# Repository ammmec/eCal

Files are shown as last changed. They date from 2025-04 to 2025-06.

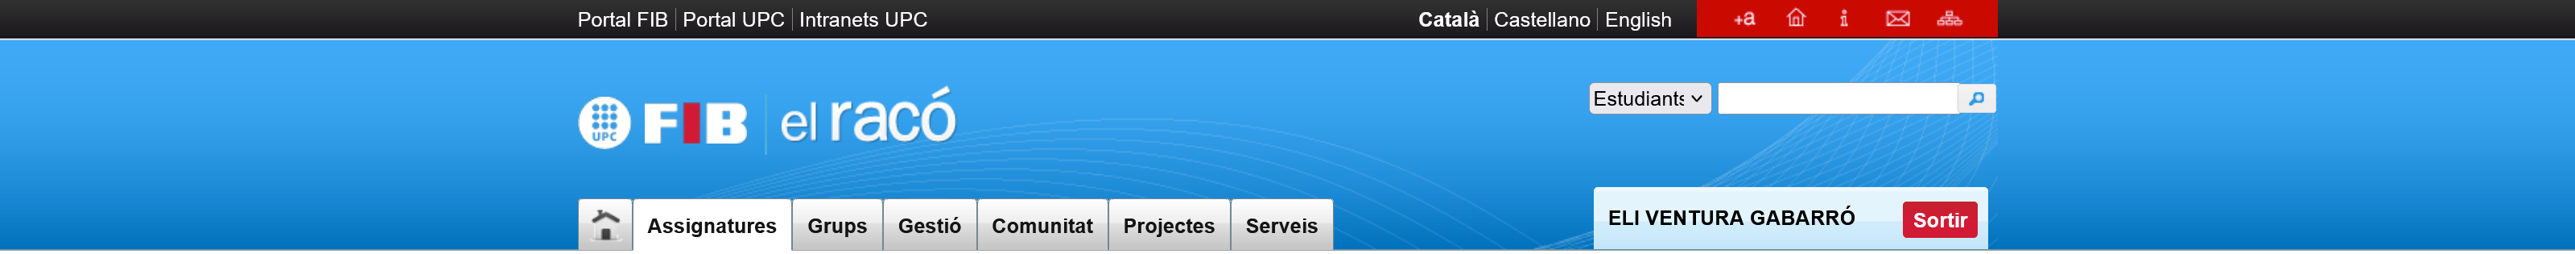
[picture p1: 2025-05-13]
raco/Racó de la FIB_fitxers/header.png

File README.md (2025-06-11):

# eCal
This repository contains the necessary source code to reproduce a dynamic e-paper classroom schedule, made as a bachelor thesis in Facultat d'Informàtica de Barcelona, UPC. It is meant for the classrooms of the faculty (FIB), but can be adapted if necessary.

## Contents
- [Features](#features)
- [Components](#components)
  * [Wiring](#wiring)
- [Project Structure](#project-structure)

## Features
- Ultra-low power.
- Long battery life.
- 3-color e-paper display (red, black & white).
- Easily rechargable.
- 3D printed fitted casing.

## Components
The following components were used to create the project:
- 7.5inch e-paper (B) by Waveshare
- Firebeetle 2 ESP32-C6 by DFRobot
- Li-Po battery 3.7V 2500mAh with JST-PH connector
- Solar Panel - 5V 60mA - 68x37mm

### Wiring
To correctly setup the device, use the following wiring:
a61561e88b862fee8ae2c5b064a682b26159ba7b
Other connections can be used, as long as the pin definition in eCal/schedule_lib.h is changed to reflect those changes.

## Project Structure
The repository has three folders. Each are linked to a specific device/server.
- [eCal](https://github.com/ammmec/eCal/tree/main/eCal): source code for the microcontroller.
- [eCal_PC](https://github.com/ammmec/eCal/tree/main/eCal_PC): source code for the daily script.
- [raco](https://github.com/ammmec/eCal/tree/main/raco): proposed addition for _el Racó_.
- [stl](https://github.com/ammmec/eCal/tree/main/stl): casing files to 3D print.
Inside the eCal and eCal_PC folders, a file needs to be added, which were ommitted in the repository for safety reasons.
The template for the file in eCal, called wifi_secure.h is the following:
```C
#ifndef WIFI_SECURE_H
#define WIFI_SECURE_H
// WiFi
inline const char* ssid = WIFI NAME GOES HERE;
inline const char* password = PASSWORD OF WIFI GOES HERE;

// MQTT Broker
inline const char *mqtt_broker = LINK TO MQTT BROKER;
inline const char *topic [] = {"+/A6/0/A6001", "+/A6/0", "+/A6", "+"};
inline const char *mqtt_username = USERNAME IN BROKER;
inline const char *mqtt_password = PASSWORD IN BROKER;
inline const int mqtt_port = BROKER'S PORT;
inline static const char ca_cert[]
PROGMEM = R"EOF(
  CERTIFICATE FOR SECURE CONNECTION
)EOF";
#endif
```
And the template for the file in eCal_PC, called data_secure.py:
```python
CLIENT_ID = PUBLIC APPLICATION OF THE RACÓ'S API

username = MQTT USERNAME
password = MQTT PASSWORD

broker = LINK TO MQTT BROKER
port = BROKER'S PORT
```

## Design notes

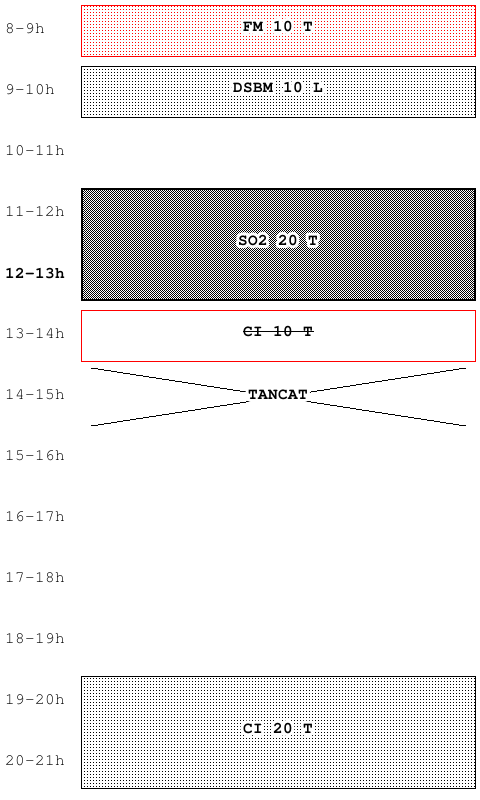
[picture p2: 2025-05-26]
eCal_PC/config/img/minimalist.png

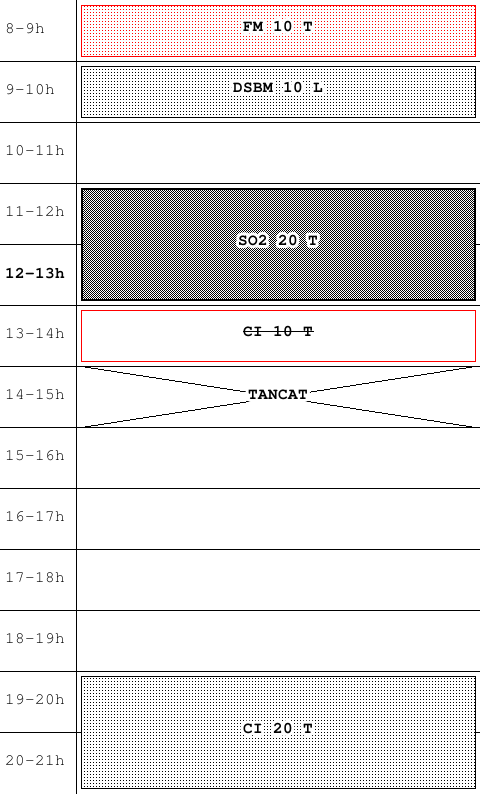
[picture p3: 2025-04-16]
eCal_PC/config/img/minimalist_lines.png

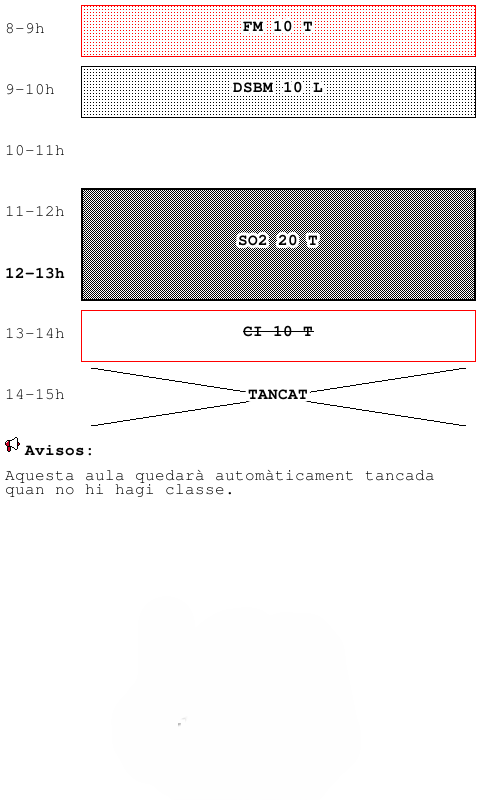
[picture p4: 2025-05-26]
eCal_PC/config/img/simple.png

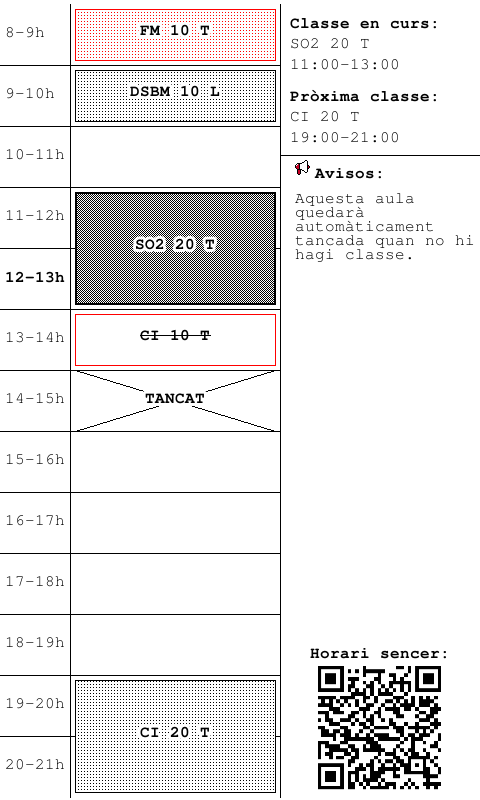
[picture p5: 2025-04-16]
eCal_PC/config/img/verbose_lines.png

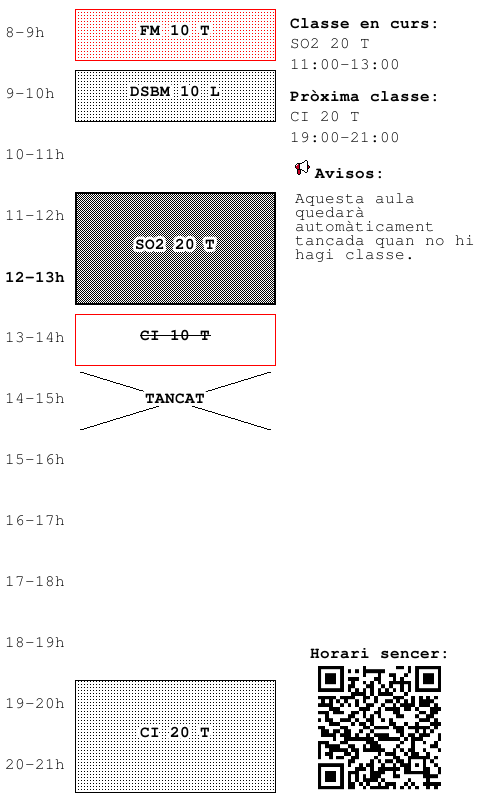
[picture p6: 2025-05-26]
eCal_PC/config/img/verbose.png

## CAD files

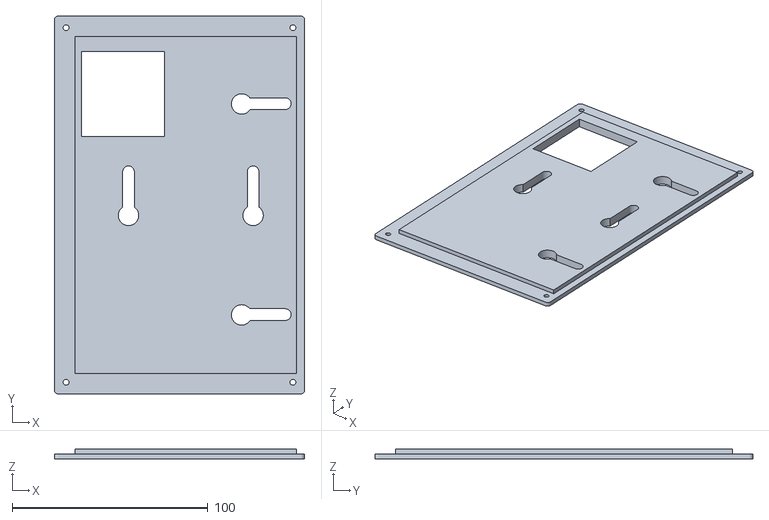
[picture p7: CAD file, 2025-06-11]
stl/Back Cover.stl
127.9 x 193.2 x 5.00

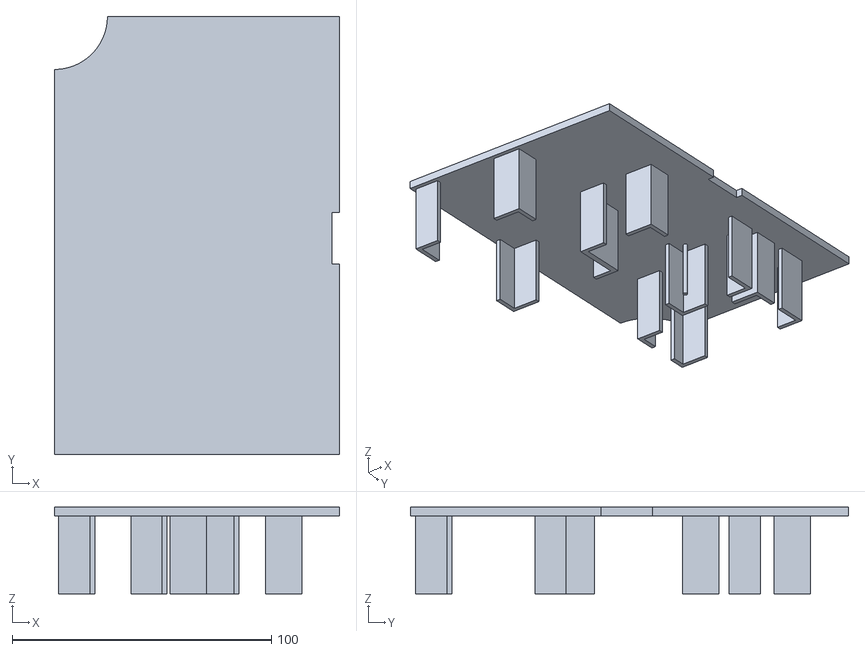
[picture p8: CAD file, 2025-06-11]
stl/Holding Section.stl
110.0 x 169.0 x 33.5

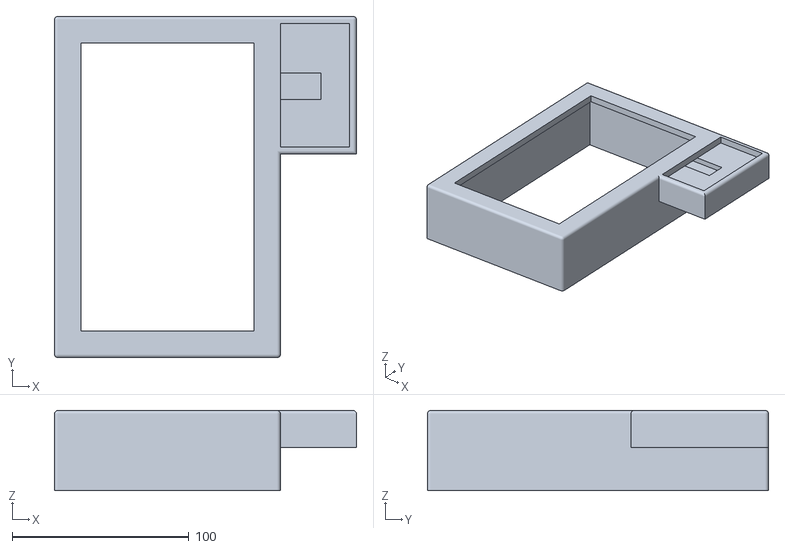
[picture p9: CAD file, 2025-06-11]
stl/Frame.stl
170.9 x 193.2 x 45.3

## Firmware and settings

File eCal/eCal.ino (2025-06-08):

#include "mqtt.h"
#define uS2M  1000000ULL*60  // 1000000ULL // Conversion from micro seconds to minutes
// Time the microcontroller will be asleep for in different moments
#define RETRY_SLEEP (((rawConfig >> 4) & 0x03F) == 0x3F) ? 5U : (rawConfig >> 4) & 0x03F  //Default value if not changed yet
#define NIGHT_SLEEP 9U                        // 10 hours (21-07): 9 + offset
#define WEEKEND_SLEEP 57U                     // 58 hours (10 for morning, 48 for weekend): 57 + offset

int16_t durations[NUM_CLASSES] = { 0, 0, 0, 0, 0, 0, 0, 0, 0, 0, 0, 0, 0 };
char classes[NUM_CLASSES][32] = { "", "", "", "", "", "", "", "", "", "", "", "", "" };
change_t changed[NUM_CLASSES] = { NONE, NONE, NONE, NONE, NONE, NONE, NONE, NONE, NONE, NONE, NONE, NONE, NONE };
char announcements[256];

RTC_DATA_ATTR bool gotSchedule = false;

void deepSleep(uint16_t minutes) {
  esp_sleep_enable_timer_wakeup(minutes * uS2M);
  #ifdef DEBUG
  Serial.println("Setup ESP32 to sleep for every " + String(minutes) + " minutes");

  Serial.println("Going to sleep now");
  #endif
  Serial.flush();
  esp_deep_sleep_start();
}

void setup() {
  #ifdef DEBUG
  Serial.begin(115200);
  delay(1000);  //Take some time to open up the Serial Monitor

  Serial.print("Good morning! Got schedule? ");
  Serial.println(gotSchedule);
  #endif

  setupLayout();

  uint8_t hourSleep = 60;
  connectWiFi(hourSleep);

  if (currentHour <= LAST_HOUR) {
    setupMQTT();

    if (!gotSchedule) {
      if (getSchedule(classes, durations)) {
        gotSchedule = true;
        needRefresh = true;
      } else {
        if (needRefresh) {
          drawNoSchedule();
          needRefresh = false;
        }
        #ifdef DEBUG
        Serial.println("Did not get schedule... Retry sleep!");
        #endif
        disconnectMQTT();
        disconnectWiFi();
        deepSleep(RETRY_SLEEP);  // If it did not manage to get the full schedule, try again after some time
      }
    }

    getDetails();
    disconnectMQTT();
    disconnectWiFi();

    // Refresh display
    #ifdef DEBUG
    Serial.println("Printing schedule");
    #endif
  
    drawSchedule(classes, durations, announcements, changed);
  }
  else {
    disconnectWiFi();

    gotSchedule = false;
    restartData(); // prepare data for a new day (e.g. initialize arrays to 0)

    if (weekday == FRIDAY) {
      #ifdef DEBUG
      Serial.println("Weekend sleep!");
      #endif
      // clearScreen();
      deepSleep(WEEKEND_SLEEP+hourSleep);
    }
    #ifdef DEBUG
    Serial.println("Night sleep!");
    #endif
    deepSleep(NIGHT_SLEEP+hourSleep);
  }

  needRefresh = false;
  #ifdef DEBUG
  Serial.println("Hour sleep!");
  #endif
  deepSleep(hourSleep);
}

void loop() {}

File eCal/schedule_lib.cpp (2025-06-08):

#include "schedule_lib.h"

// Display constructor
GxEPD2_3C< GxEPD2_750c_Z08, GxEPD2_750c_Z08::HEIGHT / 4 > display(GxEPD2_750c_Z08(/*CS=*/CS, /*DC=*/DC, /*RST=*/RST, /*BUSY=*/BUSY));  // GDEW075Z08 800x480, GD7965

uint16_t displayHeight;
uint16_t displayWidth;
LayoutConfig config;
uint16_t currentHour;
WEEKDAYS weekday = MONDAY;  // Assumes it starts on a Monday
char curr_class_pos;

// Variables to check if the schedule needs to be refreshed
char prevStartHour;
uint16_t rawConfig = 0x107F; //0b000'1'0'0'000111'1111;

bool updatedInfo = true;
RTC_DATA_ATTR bool needRefresh = true;

bool connectWiFi(uint8_t& minutesTilNextHour) {
  WiFi.begin(ssid, password);
  unsigned int startAttempt = millis();
  while (WiFi.status() != WL_CONNECTED && millis() - startAttempt < 7000) {  // Try to connect for 7 seconds. If it fails, put a WiFi error message
    #ifdef DEBUG
    Serial.print(".");
    #endif
    delay(500);
  }
  #ifdef DEBUG
  Serial.println();
  #endif
  if (WiFi.status() != WL_CONNECTED) {
    updatedInfo = false;
    return false;
  } else updatedInfo = true;
  if (minutesTilNextHour != 255) minutesTilNextHour = updateCurrentHour();
  #ifdef DEBUG
  Serial.println("\nWiFi connected.");
  #endif
  return true;
}

bool connectWiFi() {
  uint8_t dummy = 255;
  return connectWiFi(dummy);
}

void disconnectWiFi() {
  WiFi.disconnect(true);
  WiFi.mode(WIFI_OFF);
  #ifdef DEBUG
  Serial.println("Wifi disconnected.");
  #endif
}

void restartData() {
  needRefresh = true;

  // Initialize durations to 0, no changes and no announcements
  for (int i = 0; i < NUM_CLASSES; ++i) {
    durations[i] = 0;
    changed[i] = NONE;
  }
  announcements[0] = '\0';
}

// Must be called before drawing schedule for the first time. Sets up the indicated schedule
void setupLayout(uint16_t settings, bool changed) {
  Layout layout = static_cast<Layout>(settings>>13);
  bool lines = (settings>>12)&0x01;
  bool staticSchedule = (settings>>11)&0x01;
  bool saveEnergy = (settings>>10)&0x01;

  #ifdef DEBUG
  Serial.print("Layout: ");
  Serial.println(settings>>13);
  Serial.print("Lines: ");
  Serial.println(lines);
  Serial.print("SaveEnergy: ");
  Serial.println(saveEnergy);
  Serial.print("staticSchedule: ");
  Serial.println(staticSchedule);
  #endif

  display.setRotation(layout == HORIZONTAL_LAYOUT ? 2 : 1);
  displayHeight = display.height();
  displayWidth = display.width();
  if (!changed) return;

  switch (layout) {
    case DEFAULT_LAYOUT:
      config = {
        .showLines = lines,
        .showQR = true,
        .showAnnouncements = true,
        .showCurrNext = false,
        .saveEnergy = saveEnergy,
        .staticSchedule = saveEnergy || staticSchedule,  // If energy saver is on, the schedule will be static to save energy

        .numClassesDisplayed = 7,

        .topMargin = 0,
        .bottomMargin = 0,

        .endClassLine = displayWidth,
        .startAnnouncementsLine = 0,

        .name = "df"
      };
      config.classWidth = (displayWidth - config.hourLine) - (displayWidth - config.hourLine) % CLASS_BP_WIDTH;  // Take all usable space
      config.classHeight = ((displayHeight / 2) / config.numClassesDisplayed);                                   // Take half the screen
      config.rows[0] = config.classHeight * config.numClassesDisplayed + MARGIN * 3;
      break;

    case MINIMALIST_LAYOUT:
      config = {
        .showLines = lines,
        .showQR = false,
        .showAnnouncements = false,
        .showCurrNext = false,
        .saveEnergy = saveEnergy,
        .staticSchedule = false,  // Avoids a bug if it is true

        .numClassesDisplayed = 13,

        .endClassLine = displayWidth,
        .startAnnouncementsLine = 0,

        .name = "mn"
      };
      config.classHeight = (displayHeight / config.numClassesDisplayed);
      config.classWidth = (displayWidth - config.hourLine) - (displayWidth - config.hourLine) % CLASS_BP_WIDTH;
      config.bottomMargin = (displayHeight - (config.classHeight * config.numClassesDisplayed)) / 2;
      config.topMargin = config.bottomMargin + ((displayHeight - config.classHeight * config.numClassesDisplayed) % 2 != 0);
      break;

    case SIMPLE_LAYOUT:
      config = {
        .showLines = lines,
        .showQR = false,
        .showAnnouncements = false,
        .showCurrNext = false,
        .saveEnergy = saveEnergy,
        .staticSchedule = false,

        .numClassesDisplayed = 13,

        .endClassLine = displayWidth,
        .startAnnouncementsLine = 0,

        .name = "sp"
      };
      config.classHeight = (displayHeight / config.numClassesDisplayed);
      config.classWidth = (displayWidth - config.hourLine) - (displayWidth - config.hourLine) % CLASS_BP_WIDTH;
      config.bottomMargin = (displayHeight - (config.classHeight * config.numClassesDisplayed)) / 2;
      config.topMargin = config.bottomMargin + ((displayHeight - config.classHeight * config.numClassesDisplayed) % 2 != 0);
      config.rows[0] = config.classHeight * (uint16_t)((config.numClassesDisplayed + 1) / 2) + MARGIN * 3;
      break;

    case VERBOSE_LAYOUT:
      config = {
        .showLines = lines,
        .showQR = true,
        .showAnnouncements = true,
        .showCurrNext = true,
        .saveEnergy = false,  // It has to update the "current" and "next" class, can't be energy efficient
        .staticSchedule = false,

        .numClassesDisplayed = 13,

        .classWidth = (uint16_t)(CLASS_BP_WIDTH * (7.5)) - (uint16_t)(CLASS_BP_WIDTH * (7.5)) % CLASS_BP_WIDTH,

        .name = "vb"
      };
      config.classHeight = (displayHeight / config.numClassesDisplayed);
      config.bottomMargin = (displayHeight - (config.classHeight * config.numClassesDisplayed)) / 2;
      config.topMargin = config.bottomMargin + ((displayHeight - config.classHeight * config.numClassesDisplayed) % 2 != 0);
      config.endClassLine = config.startAnnouncementsLine = config.hourLine + config.classWidth + MARGIN * 2;
      config.rows[0] = (CHAR_HEIGHT + MARGIN * 2) * 7;
      config.rows[1] = displayHeight - (QR_SIZE + (CHAR_HEIGHT + MARGIN) * 2);
      break;

    case HORIZONTAL_LAYOUT:
      display.setRotation(2);
      displayHeight = display.height();
      displayWidth = display.width();

      config = {
        .showLines = lines,
        .showQR = true,
        .showAnnouncements = true,
        .showCurrNext = false,
        .saveEnergy = saveEnergy,
        .staticSchedule = staticSchedule,

        .numClassesDisplayed = 7,

        .rows = { 0, 0 },
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

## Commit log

2025-03-24 First draft MQTT DS-24
    Now the ESP32 and the PC can communicate through a free MQTT broker! I
    still have to make it manageable because it is a lot of code and I wand
    the stuff to look pretty, and also integrate more things to it, but it
    is a start!
2025-04-01 Updated .gitignore
    No more documentation folder to keep track of
2025-04-01 Silly pin test
    I needed to check all pins work, and I do not want to lose the code in
    case I have to check again. This is basically useless now but I am lazy
    to redo the code ever again.
2025-04-07 Initial schedule format
    Many things still have to be added, but this looks quite nice I think.
    Announcements and "currently"/"previous" classes still to be added
2025-04-07 Added next and current class
2025-04-11 Librarized the schedule printing
2025-05-02 Added Racós logo just in case
2025-05-26 Made debug mode
    Now it should not print anything if DEBUG is not defined :) ready for
    testing the battery
2025-06-11 Added STL files
    [Back Cover.stl, Frame.stl, Holding Section.stl]
